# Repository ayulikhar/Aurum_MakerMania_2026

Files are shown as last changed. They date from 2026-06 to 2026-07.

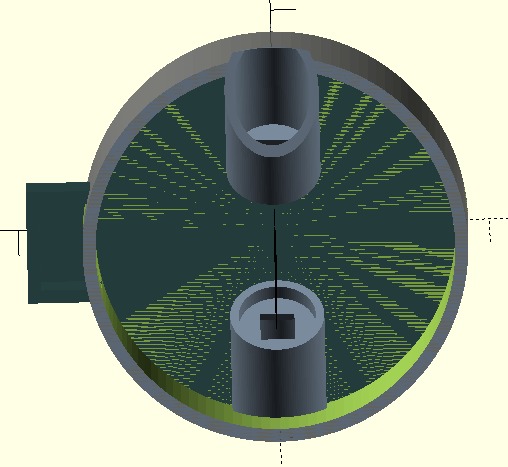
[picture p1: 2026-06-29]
images/WhatsApp Image 2026-06-24 at 1.21.38 PM.jpeg

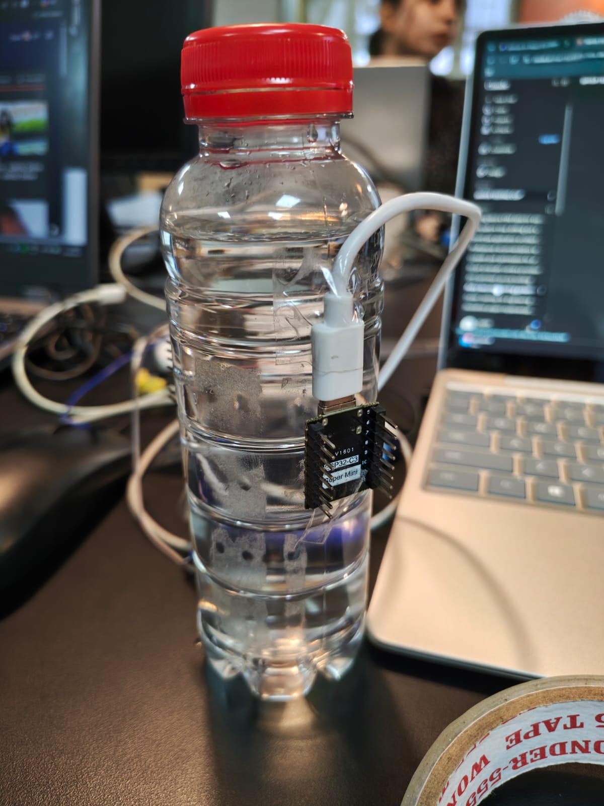
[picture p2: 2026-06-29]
images/WhatsApp Image 2026-06-27 at 2.15.06 PM.jpeg

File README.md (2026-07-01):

# Aurum MAKERMANIA 2026

## Innovation Project Workbook

> Program Duration: 1 June 2026 – 4 July 2026
>
> Location: MBF Tinkerers' Lab 007
>
> Team Size: 3–5 Students
>
> Goal: Identify a real-world problem and develop an innovative, patentable, and implementable solution.

---

# 1. Team Identity

## 1.1 Team Name and Photo
WhatsApp Image 2026-06-06 at 12 39 31 PM

---

## 1.2 Team Members

| Name | Role | Skills |
| ---- | ---- | --- |
| Ayush Likhar | Collaborator | Hardware |
| Kartik Phadale | Collaborator | Software |
| Meezaan Malik | Collaborator | Design |

---
# Useless Product Link
https://youtu.be/-Jjdkq18U_4
---
# SCAMPER PROJECT 
https://1drv.ms/p/c/c6b1c4d0bfa1a2d2/IQAcbvFI4a4YR6u9E6l7ya9vAZwWg2kD-QSHdWZtFSUPwtM?e=thSRv1
---
# 2. Problem Discovery

## 2.1 Observation Area

Where did you conduct your observations?

* Hostel
* Canteen
* Workshop
* Hospital
* Public Transport
* Home
* Other

---

## 2.2 AEIOU Observation Sheet

### Activities

What are users doing?

Filling drinking water from taps, borewells, or overhead tanks before consuming
Storing water in containers such as pots, buckets, and plastic cans for daily household use
Manually checking water appearance against light or checking by smell before use
Operating water purifiers (RO/UV) with little understanding of actual output quality
Buying packaged drinking water due to distrust of the tap supply

### Environment

What conditions affect them?

Urban apartments and peri-urban areas with inconsistent municipal supply quality
Rural homes relying on borewell or hand-pump water with unknown contamination levels
Post-monsoon periods where sediment and biological load spike in surface water
Kitchens and storage areas where any device must survive humidity and incidental water exposure
Frequent power outages in many regions, meaning the device cannot depend on mains supply during testing

### Interactions

Who or what are they interacting with?

Water sources including taps, tanker trucks, borewells, and stored containers
Household members, particularly mothers making water safety decisions for children
Water purifiers (RO/UV) that users trust without verifying actual output quality
Municipality or tanker suppliers, where complaints are made verbally with no data to support them
Neighbours and community members, through informal word-of-mouth about water quality

### Objects

Plastic storage containers and overhead tanks as primary water holding vessels
RO/UV purifiers that are trusted but unmonitored for actual output quality
TDS pen meters used by some urban households, though the numeric output is rarely understood
Packaged water bottles purchased as a costly substitute when tap water is distrusted
No pH or turbidity measurement tools are present in a typical household — this is the gap this device addresses

### Users

Homemakers (25–55 years): primary decision-makers for household drinking water, generally non-technical
Renters in urban areas: no control over plumbing infrastructure, high need to verify supplied water
Rural households: borewell-dependent, no access to laboratory testing, often low literacy
Parents with young children: heightened concern, willing to act on clear safety signals
Small food businesses such as tea stalls and tiffin centres needing quick, repeatable daily water checks

---

## 2.3 Observation Log

| Observation | Evidence | Pain Point |
| --- | --- | --- |
| | | |
| | | |

---

# 3. User Research

## 3.1 Interview Summary

Number of users interviewed: ______

## 3.2 Key Quotes

1.

2.

3.

---

## 3.3 User Persona

### Name

### Age

### Occupation

### Goals

### Frustrations

### Needs

---

# 4. Problem Framing

## Problem Statement

Household users, particularly in Indian urban and semi-urban contexts, have no affordable, reliable, and easy-to-use tool to simultaneously assess multiple water quality parameters at the point of use. As a result, they either consume potentially unsafe water without knowing it, or spend unnecessarily on packaged alternatives. Existing solutions are either single-parameter, too expensive, or require technical knowledge to interpret.

---

## How Might We Questions

1. How might we make water quality assessment as simple as filling a cup, with no technical skill required?
2. How might we measure pH, turbidity, and TDS simultaneously without submerging any electrical components in the water?
3. How might we deliver a multi-parameter water quality device at a unit cost low enough for household adoption across income levels?
---

## Opportunity Ranking

| Criteria | Score |
| --- | ----- |
| Severity | 9 |
| Frequency | 9 |
| Feasibility | 7 |
| Novelty | 9 |
| Market Potential | 8 |
| Total | 42 |

---

# 5. Solution Ideation

## Brainstormed Ideas

| Idea | Advantages | Challenges |
| ---- | --- | --- |
| Arterial Aging Ring  | Can detect arterial health, blockages  | Miniature, Accuracy |
| Compression Stockings | Varicose Veins Relief | Graduated compression accuracy, cost-effective production |
| Trash Compactor | Increased Storage Efficiency, Odour Removal  | Proof of Concept |
| River Cleaaning UAV | Pilotless water body cleaning | Limited large-scale capacity, autonomous navigation challenges |
| Touch Sensing Glove with Haptics | Brings Realistic Feedback | Application and comfort Challenges |
| Tamperproof Weighbridge | Ensures fraud free loading | System Integration |

---

## Selected Concept

Waterborne illness remains a leading cause of disease in Indian households. Simultaneously, no single affordable device measures all critical parameters together. Water can pass TDS comfortably and still be dangerously acidic or heavily contaminated with fine particulates. The parameters are interdependent but are currently measured in isolation if at all. 
Each subsystem is a self-contained learning module. The TDS refractometry covers physical optics and numerical methods. Turbidity covers photonics and analog circuit design. Together they represent a systems integration challenge that mirrors professional product development. 

---

# 6. System Design

## High-Level Description

The solution provides a cup-based turbidity testing system that accepts a water sample, measures its cloudiness through an embedded sensor, and displays or transmits the resulting water quality assessment.

---

## Block Diagram



---

## Inputs

|Input | Importance |
|---- |--- |
| Water Sample in Cup | Main physical input |  
| Colorimetry | pH Value |
| RGB Sensor | pH level determination |
| nRF24L01  | Transmission of EM waves |

---

## Outputs

| Sensors | Output |
|----- |----- |
|LCD / Display Output | Turbidity reading, clarity percentage, status (clear, cloudy, dirty) |
|Buzzer | Alert |

---

# 7. Technical Planning

## Electronics

| Component | Purpose |
| --- | --- |
| ESP32 NodeMCU Development Board | System timing, nRF24 SPI interface, I2C polling, hardware timers for optical tracking |
| ADS1115 16-Bit I2C ADC Module | Overcomes the noisy, non-linear internal ADC of the ESP32 to capture microvolt changes from the custom pH sensor |
| Double-Sided Copper-Clad PCB Board Blank | Slashed into small rectangles to create the physical sensing pad and reference pad surfaces.  |
| Concentrated Sodium Hypochlorite (Bleach) + Sandpaper | Used as an oxidizer on the copper track to grow the reactive copper-oxide (CuO) sensing layer|
| 5V 650nm Red Laser Diode (6mm diameter, 5mW) |Projects a tight optical beam through the diagonal entry tunnel. |
| Glass Microscope Coverslips (0.13 - 0.17mm thick) | Acts as the optically flat, scratch-resistant window sealed into the 45-degree pocket |
| TSL1401CL Linear Photodiode Array (128 Pixels) | Captures the high-resolution spatial displacement of the laser beam spot down to fractional subpixels |
| Dual Light-Dependent Resistors (LDRs) + Razor Blade | Ultra-scalable alternative: Two matching LDRs separated by an opaque blade edge to form a basic analog differential balance pair |
| 2x nRF24L01+ 2.4 GHz Transceiver Modules | Mounted entirely outside the cup walls to measure signal amplitude drop (RSSI) through the liquid column.|
| 2x 2.4 GHz PCB Directional Patch Antennas | Focuses the RF energy straight through the liquid column, minimizing external multipath interference |
| DS18B20 Waterproof Temperature Probe | Real-time thermal tracking to dynamically recalculate the temperature-dependent Nernst slope for the pH firmware|
| Assorted Resistors (10kΩ, 4.7kΩ), 0.1µF Capacitors | Pull-up resistors for the 1-Wire temperature bus, voltage dividers for LDR paths, and decoupling caps for RF rails |
| Clear Marine-Grade Silicone RTV or 2-Part Transparent Epoxy | Creates a reliable waterproof seal around the glass coverslip insert and wire pass through tunnels |
| Turbidity Sensor with Module | Measures water clarity by dropping an infrared emitter/receiver probe directly into the liquid. |
| pH-4502C Liquid pH Sensor Module + E-201-C Glass Combination Electrode | Measures hydrogen ion activity using a traditional glass bulb probe with a BNC connector interface board 
| TP4056 , Lipo cells | |

---
## Software

| Tool | Purpose |
| ---- | --- |
| KiCAD |  PCB Design |
| OpenSCAD | 3D Model Design  |
| BambuLab | 3D print  |

---

## Mechanical / CAD

WhatsApp Image 2026-06-24 at 1 21 38 PM (1)

A vertically oriented, two-section cylindrical assembly designed to house a multi-parameter water quality sensing system. The complete assembly stands 190 mm tall. A hollow open-top cylinder of 140 mm height forming the primary water-holding vessel. The inner diameter provides sufficient water volume for accurate optical measurements while maintaining a compact handheld form factor.                                                                             The floor of the cup body incorporates a raised conical deflector structure housing two laser alignment tunnels, each inclined at 45° to the vertical axis.  A large curved ramp surface sweeps from the inner wall down toward the central aperture, redirecting the laser beam from its horizontal entry path to a 45° angle through the water column. A second symmetric tunnel on the opposite side captures the refracted beam and routes it to the external photo diode array. The floor geometry is fully integrated into the cup body as a single printed part, eliminating alignment error between the optical axis and the deflector surface. The housing sits on a flat circular base and contains the primary electronics bay for the ESP 32 micro-controller, signal conditioning circuitry, and power management components. Four rectangular extrusions protrude from the outer diameter of the assembly at the cup-to-housing interface, each 40 mm in length and separated by 10 mm gaps. These housings accommodate the lateral optical and sensing components 

---

# 8. Prototype Development

## Version 1

Description: 

Two ESP32-C3 Supermini boards configured in an ESP-NOW Master-Slave architecture, placed on opposite sides of a water-filled cup. The Master transmitted packets at fixed maximum TX power while the Slave measured RSSI values, attempting to correlate signal attenuation with turbidity levels.

Lessons Learned:
- RSSI behaved opposite to expectation — signal was stronger through turbid water than clean water due to particles displacing water and reducing bulk dielectric loss
- At drinking water turbidity ranges (0–500 NTU), particle volume fraction is below 0.002%, making the dielectric change too small to detect within ESP32's 1 dBm RSSI resolution floor
- RF signal leaked around the water container rather than through it, meaning ambient reflections from walls and surfaces dominated the readings
- This is a fundamental physics constraint, not a fixable engineering or code problem
---

## Version 2

Description:
Same ESP32-C3 Supermini hardware reprogrammed with a power sweep method. Instead of reading RSSI, the Master stepped TX power down from 21 dBm to 5 dBm in 8 discrete levels, sending 10 packets at each level. The Slave sent ACK packets back reporting reception count per level. The power threshold at which packet reception dropped below 50% was used as a turbidity proxy.

Lessons Learned:

- Channel mismatch error (Peer channel is not equal to home channel) required switching from WiFi.channel() to esp_wifi_set_promiscuous() + esp_wifi_set_channel() for correct channel locking
- Power sweep output was identical regardless of water presence, turbidity level, or board orientation — confirming that even the binary threshold method cannot resolve turbidity changes at the signal magnitudes available over a 5cm path at 2.4GHz
- RF shielding with aluminum foil was attempted to force signal through water only, with no measurable improvement
- The 103 dBm of remaining link budget after water attenuation is too large — turbidity-induced loss is buried orders of magnitude below the noise floor
---
DOCUMENTATION LINK: <https://docs.google.com/document/d/1FKyJl6S2ex2YoXibOfduwqcpoKrc6gzWdBtXB66RiD4/edit?usp=sharing>
## Final Prototype

Description:

In progress
---

# 9. Testing & Validation

## Testing Plan

| Test | Success Criteria |
| ---- | --- |
| | |
| | |

---

## User Feedback

| User | Feedback | Action Taken |
| ---- | --- | --- |
| | | |

---

# 10. Innovation Assessment

## Existing Solutions

List competing products.

---

## What Makes This Different?

---

## Innovation Score

| Parameter | Score |
| --- | ----- |
| Novelty | |
| Technical Depth | |
| Feasibility | |
| Impact | |
| Scalability | |

---

# 11. Intellectual Property

## Prior Art Search

Patents / Products Found:

---

## Novel Features

1.

2.

3.

---

## Provisional Patent Draft

### Title

### Abstract

### Problem

### Solution

### Claims

---

# 12. Business & Deployment

## Target Users

---

## Estimated Cost

---

## Market Opportunity

---

## Sustainability Considerations

---

# 13. Final Demonstration

## Prototype Images

Insert photos.

---

## Demonstration Video Link

---

## GitHub Repository

---

## Presentation Link

---

# 14. Reflection

## What Worked Well?

---

## What Failed?

---

## Key Learnings

---

## Next Steps

* Patent Filing
* Startup Exploration
* Product Development
* Research Publication
* Competition Submission

---

# 15. Final Deliverables Checklist

* Problem Discovery Complete
* User Interviews Complete
* Persona Created
* Problem Statement Finalized
* System Design Complete
* Prototype Demonstrated
* Testing Completed
* Patent Draft Prepared
* Presentation Submitted
* GitHub Repository Updated

---

# MAKERMANIA FINAL PITCH

Each team will present:

1. Problem
2. User Research
3. Insights
4. Solution
5. Prototype Demo
6. Innovation & Patentability
7. Future Roadmap

Presentation Time: 5 Minutes

Q&A: 3 Minutes

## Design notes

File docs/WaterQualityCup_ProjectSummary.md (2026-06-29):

# Solid-State Water Quality Testing Cup
## Project Summary — Teammate Reference Document

> **Purpose:** This document summarises all design decisions, physics, firmware, hardware, and experimental results from the project development chat. Use this as your starting point for continuing work.

---

# SECTION 1 — PROJECT OVERVIEW

## Core Concept
A multi-parameter water quality testing device shaped like a cup. The defining engineering constraint is **100% solid-state, non-contact architecture** — no electrodes, no glass probes, no electrical contact between sensing electronics and the water being tested.

## Why This Architecture
- Eliminates ground loops between sensors when multiple are submerged together
- Eliminates sensor fouling (probes getting dirty)
- Eliminates fragile glass pH bulbs
- Drives unit cost toward mass-manufacturing economics
- Genuinely novel — no prior art found for this specific combination

## Three Sensing Subsystems

| Subsystem | Parameter | Method |
|---|---|---|
| A | Turbidity | RF attenuation / CSI phase (2.4GHz) |
| B | TDS (Total Dissolved Solids) | Dual-wavelength laser refractometry |
| C | pH, Chlorine, Hardness | Optical colorimetry (phenol red dye + RGB sensor) |

---

# SECTION 2 — PATENT STATUS

## Patentability Assessment (India, Patents Act 1970)

| Subsystem | Novelty | Strength |
|---|---|---|
| RF/CSI turbidity method | High — no prior art found | Strongest independent claim |
| Laser refractometry TDS (specific geometry) | Medium — principle known, geometry novel | Strong dependent claim |
| Colorimetric pH (ratiometric spectral) | Low standalone | Part of combination claim |
| Entire cup system (combination) | High | Primary patent claim |

## Key Filing Facts
- **No prototype required** for provisional filing
- Theory, mathematics, and figures are sufficient at provisional stage
- File provisional first (costs ~₹1,600 on IP India portal)
- 12-month window after provisional to build PoC and file complete specification
- **Do not publish or present publicly before filing**

## Provisional Specification Must Include
1. Cross-section diagram of cup with all three subsystems labelled
2. Block diagram of electronics
3. Mathematical description of each sensing method
4. RF attenuation theory + calibration curve concept
5. Snell's Law geometry for refractometry
6. RGB-to-HSV or ratiometric spectral conversion for pH
7. Informal claims list (formal claims required only in complete spec)

## Strongest Patent Claims
1. The cup-form-factor solid-state multi-parameter sensing architecture
2. RF/CSI-based non-contact turbidity sensing through cup walls
3. Dual-wavelength refractometry with mathematical temperature/TDS decoupling
4. Ratiometric spectral pH using dissolved indicator dye

---

# SECTION 3 — HARDWARE ARCHITECTURE

## Microcontrollers

| Board | Role | Notes |
|---|---|---|
| ESP32-C3 Supermini #1 | RF Turbidity — Master/Tx | Transmits ESP-NOW beacons through water |
| ESP32-C3 Supermini #2 | RF Turbidity — Slave/Rx | Measures RSSI / CSI, outputs to Serial Monitor |
| ESP32 DevBoard (38-pin, black) | Master MCU | Runs TDS, colorimetric, OLED, BLE |

## Critical Arduino IDE Settings (Both ESP32-C3 Boards)
```
Board:              ESP32C3 Dev Module
USB CDC On Boot:    Enabled  ← MANDATORY or Serial won't work
Upload Speed:       115200
Flash Mode:         DIO
Partition Scheme:   Default 4MB with spiffs
Core version:       3.0.0 or higher  ← MANDATORY for rx_ctrl->rssi
```

## Known Firmware Issues Fixed
- `BOOT_PIN` conflicts with `esp32-hal.h` → renamed to `BTN_BOOT`
- Send callback must use `wifi_tx_info_t*` not `uint8_t*` in core v3
- No `ARDUINO_ISR_ATTR` on ESP-NOW callbacks
- USB-CDC needs 2–3 second wait loop in `setup()` before Serial output

---

# SECTION 4 — TURBIDITY SUBSYSTEM (RF / CSI)

## Current Status: RSSI Method Has Physics Problems

### What Was Tested
Two ESP32-C3 Superminis mounted on opposite sides of a 5cm diameter PET bottle filled with water. ESP-NOW packets fired at 20/second. RSSI measured from `recv_info->rx_ctrl->rssi` in receive callback.

### Experimental Results
```
Clean water:          -38 dBm baseline (through cup, correct geometry)
Turbid water (flour): -25 dBm (RSSI went UP — wrong direction)
Air (no water):       -29 dBm
```

### Why RSSI Goes The Wrong Direction
At 2.4GHz, **water is the absorber, not the particles.** Adding suspended particles displaces water molecules, reducing bulk dielectric loss of the mixture. More particles = less water in path = less RF absorption = RSSI increases. Particle scattering is negligible because particles (0.1–100µm) are 100–10,000× smaller than the 14.2mm wavelength inside water at 2.4GHz.

### Why Signal Magnitude Is Too Small
At 100 NTU, particles occupy < 0.002% of water volume. The resulting dielectric change is below the ESP32's 1 dBm RSSI resolution floor. This is a fundamental physics constraint, not a fixable engineering problem.

### Physical Setup Problems Found
- Pin headers created air gap between boards and bottle → RF leaked around water
- Reflected paths from desk/laptop/walls dominated over direct through-water path
- No RF shielding on sides of bottle
- Cupping hands helped identify but did not resolve the direction issue

## Three Viable Solutions

### Solution A — Power Sweep Threshold (Implement Now, Same Hardware)
Instead of reading RSSI amplitude, step transmit power down in known increments and find the link margin threshold — the minimum power at which the Slave still receives packets. More turbid water requires higher transmit power to maintain the link.

- Resolution: ~500 NTU (not drinking-water precise)
- Cost: ₹0, same hardware, implementable today
- Patent value: Medium

```cpp
// Master sweeps TX power from max to min
// Slave reports packet reception rate at each power level
// Threshold power = turbidity proxy
const int8_t powerLevels[] = {20, 28, 40, 52, 60, 68, 76, 84}; // ×0.25 dBm
```

### Solution B — LoRa at 868MHz (Better Physics)
At 868MHz, water's dielectric loss is lower, so turbidity signal is relatively larger. Replace ESP32-C3 nodes with SX1276 LoRa modules.
- Cost: ~₹400 for two modules
- Resolution: Better than 2.4GHz, still not NTU-precise
- Patent value: Medium

### Solution C — ESP32 CSI Phase Measurement (Best, Recommended)
**Channel State Information (CSI)** from the ESP32's WiFi radio includes per-subcarrier phase data. Phase changes more than amplitude when turbidity changes because particles affect the real part of permittivity (ε') which RSSI cannot see.

- Requires: Full ESP32 or ESP32-S3 (NOT ESP32-C3 — C3 does not support CSI)
- Your existing black 38-pin ESP32 DevBoard supports CSI
- Resolution: ~100–200 NTU threshold (far better than RSSI)
- Cost: ₹0 — use existing DevBoard
- Patent value: **Strong** — CSI-based liquid turbidity sensing is novel, published research supports the physics

**Recommended next step: Implement CSI on the ESP32 DevBoard.**

## RSSI Firmware (Current Working Code)

### Flashing Order
1. Flash `GET_MAC.ino` to Slave → write down MAC address printed
2. Flash `MASTER.ino` to ESP32-C3 #1 (paste Slave MAC first)
3. Flash `SLAVE.ino` to ESP32-C3 #2
4. Power Master from USB power bank; Slave stays connected to PC

### Key Code Facts
```cpp
// Slave receive callback — RSSI extraction
void onPacketReceived(const esp_now_recv_info_t *recv_info,
                      const uint8_t *data, int len) {
    int8_t rssi = recv_info->rx_ctrl->rssi;  // Range: -120 to 0 dBm
    // Store in ring buffer for median filtering
}

// Master send callback — CORRECT v3 signature
void onPacketSent(const wifi_tx_info_t *info,        // NOT uint8_t*
                  esp_now_send_status_t status) { }

// Both boards must use same channel
const uint8_t WIFI_CHANNEL = 1;  // Change if WiFi congestion on ch.1

// Buffer size increased to 40 (no decoupling caps available)
const uint8_t RSSI_BUFFER_SIZE = 40;
```

### NTU Conversion (After Calibration)
```
NTU = A × RSSI² + B × RSSI + C
```
Coefficients A, B, C are placeholders (0.0) until lab calibration with known NTU standards. RSSI values are real and accurate immediately.

### Temperature Compensation
```
RSSI_compensated = RSSI_raw - (K_TEMP × (T_water - 25.0))
K_TEMP = 0.2 dBm/°C (starting estimate, refine during calibration)
Apply compensation BEFORE polynomial conversion, not after.
```

---

# SECTION 5 — TDS SUBSYSTEM (LASER REFRACTOMETRY)

## Physics

The cup has a 45° diagonal laser tunnel. The laser enters the water perpendicular to the 45° glass coverslip (zero bending at entry). The beam travels at 45° through the water and exits through the opposite cup wall at ~70° from horizontal.

**Key geometric advantage:** At 70° exit angle, the geometric amplification factor is 8.7×, giving ~60µm beam displacement per 1000 ppm TDS at 20mm detector standoff. This is detectable with the BPW34 differential pair.

## Dual-Wavelength Method

Two lasers (650nm red + 405nm violet) travel the same path. They exit at slightly different angles due to chromatic dispersion:
```
Red (650nm):    exit angle = 70.2°
Violet (405nm): exit angle = 71.8°
Spot separation at 20mm standoff: 6.2mm vertical
```

### Why Two Wavelengths
1. **Mechanical noise cancellation:** Both beams shift equally when cup vibrates — their separation is immune to physical disturbance
2. **Temperature/TDS decoupling:** TDS and temperature affect the two wavelengths in different ratios, allowing a 2×2 matrix solve for both simultaneously — no temperature sensor required
3. **Stronger patent claim:** Novel dual-observable ratiometric measurement

### 2×2 Matrix Solution
```
D_red    = α_red    × ΔTDS + β_red    × ΔT
D_violet = α_violet × ΔTDS + β_violet × ΔT

Constants:
α_red    = 1.65×10⁻⁷  (dn/dC at 650nm, per ppm)
α_violet = 1.80×10⁻⁷  (dn/dC at 405nm, per ppm)
β_red    = -9.5×10⁻⁵  (dn/dT at 650nm, per °C)
β_violet = -10.0×10⁻⁵ (dn/dT at 405nm, per °C)
DET      = (α_red × β_violet) - (α_violet × β_red) = 6.0×10⁻¹⁴

Solve by Cramer's Rule:
ΔTDS = (β_violet × dn_red - β_red × dn_violet) / DET
ΔT   = (α_red × dn_violet - α_violet × dn_red) / DET
```

## Detector: BPW34 Differential Pair (Replaces TSL1401CL)

TSL1401CL was not available. BPW34 differential pairs are used instead — actually better for small displacement signals.

```
Two BPW34 diodes mounted vertically (PD_A above PD_B)
Gap between faces: 0.3–0.5mm (use cardstock shim during assembly)
Red cellophane filter over red pair
Violet cellophane filter over violet pair
Gap must be VERTICAL because beam moves vertically with TDS change

Signal: (I_A - I_B) / (I_A + I_B)
Ratiometric — immune to laser power drift
```

## Signal Conditioning Circuit
```
BPW34 → LM358 TIA (transimpedance amplifier)
Feedback resistor: 1MΩ
Stability capacitor: 10pF across feedback resistor
Output voltage: I_photodiode × 1MΩ
ESP32 ADC reads output voltage (GPIO32, 33, 34, 35 — all ADC1)
```

## Coverslip Alignment Test
```
Shine laser through tunnel with coverslip in place (dry, no water)
If reflection goes straight back into laser tunnel → coverslip angle correct ✅
If reflection goes sideways → adjust coverslip angle with paper shim ❌
Perpendicular incidence produces retroreflection
```

## Calibration
Prepare NaCl solutions at 100, 250, 500, 1000, 2000 ppm.
Record differential ratio at each concentration.
Run Python regression to find K_SENS_RED and K_SENS_VIOLET.
Use Cramer's Rule to solve for TDS and temperature simultaneously.

---

# SECTION 6 — pH SUBSYSTEM (COLORIMETRY)

## Method: Phenol Red Dissolved Dye + TCS34725 RGB Sensor

Add a microdrop of phenol red solution to the water sample. The dye changes colour based on pH:
```
pH < 6.8  → Yellow
pH = 7.0  → Orange
pH > 8.4  → Red
```
This range (6.8–8.4) covers the entire WHO drinking water acceptability window exactly.

## Why Not Test Strips
- Strips cost ₹2–5 each; phenol red costs < ₹0.05/test
- Dissolved dye gives uniform optical path; strips have uneven surfaces
- Phenol red shelf life: 3–5 years

## Where to Get Phenol Red in Mumbai
- SRL Chemicals / Byculla chemical market
- HiMedia, Merck India on IndiaMART
- Your college biology/microbiology lab likely has it — ask before buying

## Ratiometric pH Calculation
```cpp
// TCS34725 reads R, G, B, Clear channels
// Normalise against Clear to remove LED intensity dependence
float rNorm = (float)r / (float)c;
float bNorm = (float)b / (float)c;

// Ratio rises monotonically with pH
float ratio = rNorm / (rNorm + bNorm);

// Convert to pH via calibration polynomial
float pH = (CAL_A * ratio * ratio) + (CAL_B * ratio) + CAL_C;
```

Using ratio instead of raw values makes reading immune to LED brightness variation — same principle as HSV hue method.

## Accuracy
- TCS34725 + phenol red + ratiometric: ±0.2–0.4 pH
- Better than test strips (±0.5–1.0)
- Sufficient for WHO 6.5–8.5 drinking water standard

## Calibration Required
pH 4.0, 7.0, and 10.0 buffer sachets (~₹80 each, one-time purchase).
Dissolve phenol red in each buffer at same concentration as your measurement setup.
Record ratio value for each known pH.
Fit 2nd-order polynomial in Python.

---

# SECTION 7 — CUP DESIGN (3D PRINTED)

## Already Built Features
- 45° diagonal laser tunnel (sealed, light-tight)
- Glass coverslip pocket at base of tunnel (45° angle)
- Two rectangular side cutouts for RF node mounting
- Circular colorimetric sensor window on side wall
- Removable base plate for assembly access

## Confirmed Beam Path
- Laser enters water perpendicular to 45° coverslip → no bending at entry
- Beam travels at 45° through water column
- Exits through opposite cup wall at ~70° from horizontal
- All refraction happens at the exit wall — this is where TDS is measured

## Detector Standoff Bracket (To Be Printed)
- Mounts on outside of cup wall opposite laser tunnel
- 20mm standoff from outer wall surface to photodiode faces
- Upper position: violet BPW34 pair
- Lower position: red BPW34 pair
- Vertical separation between pair centres: 6.2mm

## Assembly Sequence
```
1. Install coverslip → verify with retroreflection test
2. Install laser in tunnel → dry fire, confirm beam exits
3. Physical beam trace → mark exit point on cup wall
4. Assemble BPW34 pairs → mount at exit point
5. Wire to LM358 TIA circuit on external perfboard
6. Connect to ESP32 ADC
7. Fill with distilled water → run baseline calibration
8. Fill with known NaCl solutions → derive K_SENS
9. Install RF nodes in side pockets
10. Install TCS34725 + phenol red at colorimetric window
```

---

# SECTION 8 — COMPLETE BILL OF MATERIALS

| # | Component | Spec | Qty | Est. Cost (₹) |
|---|---|---|---|---|
| 1 | ESP32-C3 Supermini | 2.4GHz, ESP-NOW | 2 | 360 |
| 2 | ESP32 DevBoard (black) | 38-pin, dual-core | 1 | 350 |
| 3 | TCS34725 RGB sensor | I2C, IR filter | 1 | 280 |
| 4 | Laser diode, 650nm red | 5mW, 5V, with driver | 1 | 100 |
| 5 | Laser diode, 405nm violet | 5mW, 5V, with driver | 1 | 200 |
| 6 | BPW34 photodiode | Silicon PIN, TO-5 | 4 | 112 |
| 7 | Silicone sealant | Neutral cure, clear | 1 tube | 120 |
| 8 | 100µF electrolytic cap | 10V, radial | 2 | 10 |
| 9 | 100nF ceramic cap | 50V | 4 | 8 |
| 10 | 10µF electrolytic cap | 10V, radial | 4 | 20 |
| 11 | LM358 dual op-amp | DIP-8, single supply | 2 | 24 |
| 12 | Resistor 1MΩ | ±1%, 0.25W | 8 | 8 |
| 13 | Resistor 10kΩ | ±5%, 0.25W | 3 | 3 |
| 14 | Resistor 470Ω | ±5%, 0.25W | 3 | 3 |
| 15 | Resistor 330Ω | ±5%, 0.25W | 5 | 5 |
| 16 | N-MOSFET 2N7000 or BS170 | TO-92 | 3 | 24 |
| 17 | Microscope coverslips | 22×22mm, #1 thickness | 1 pack (50) | 120 |
| 18 | White LED, high CRI | CRI≥90, 5600K | 2 | 30 |
| 19 | Phenol red powder | Lab grade, 5g | 1 | 150 |
| 20 | pH buffer sachet pH 4.0 | Calibration standard | 1 | 80 |
| 21 | pH buffer sachet pH 7.0 | Calibration standard | 1 | 80 |
| 22 | pH buffer sachet pH 10.0 | Calibration standard | 1 | 80 |
| 23 | Clear acrylic sheet, 3mm | Cut to 30×20mm | 1 piece | 30 |
| 24 | 18650 Li-Ion cell | 3.7V, ≥2000mAh | 1 | 200 |
| 25 | TP4056 charging module | With protection | 1 | 35 |
| 26 | MT3608 boost converter | 3.7V→5V adjustable | 1 | 45 |
| 27 | 7semi / AMS1117-3.3V LDO | 1A output | 1 | 15 |
| 28 | OLED display | 0.96", SSD1306, I2C | 1 | 120 |
| 29 | Jumper wires | M-M and M-F, 20cm | 1 set | 60 |
| 30 | Breadboard | 830 tie-points | 1 | 80 |
| 31 | Perfboard | 5×7cm | 2 | 50 |
| 32 | 5-minute epoxy | Two-part, clear | 1 pack | 80 |
| 33 | M2 screws and nuts | 6mm | 1 pack | 30 |
| 34 | NaCl (table salt) | Food grade | 1 pack | 20 |
| 35 | Kaolin clay | Fine powder | 100g | 50 |
| 36 | Distilled water | 1 litre | 2 bottles | 50 |
| | **TOTAL** | | | **~₹3,050** |

## LDO Note
AMS1117-3.3V and 7semi 5V→3.3V 1A LDO are functionally identical for this application. Use whichever is available. Neither is needed for the turbidity prototype (both C3 Superminis self-regulate from USB). Only needed when full sensor suite is connected to DevBoard.

## Capacitor Note
100pF capacitors (currently available) are useless for power decoupling — too small by 3–6 orders of magnitude. Work without capacitors for now by:
- Powering Master and Slave from separate USB sources
- Increasing RSSI_BUFFER_SIZE to 40 in firmware
- Order 100µF and 100nF caps with next component batch

---

# SECTION 9 — POWER ARCHITECTURE

```
18650 Li-Ion (3.7V)
        │
        ├──→ TP4056 (charging)
        │
        ├──→ MT3608 Boost → 5V rail → Lasers + White LED
        │                             (gated via MOSFET)
        │
        └──→ ESP32 DevBoard VIN → onboard AMS1117 → 3.3V
                                   → Sensors (TCS34725, OLED, BPW34 circuit)
```

ESP32 DevBoard has its own onboard LDO. External LDO only needed for a dedicated clean analog sensor rail separate from the DevBoard's noisy WiFi-sharing rail.

---

# SECTION 10 — CALIBRATION PROCEDURES

## Turbidity (RF — After Physics Solution is Chosen)
1. Prepare kaolin clay suspensions at 0, 50, 100, 250, 500 NTU
2. Get reference NTU values certified by a water testing lab (CPCB lab)
3. Record RSSI (median) for each standard at 25°C
4. Run Python polynomial regression → get A, B, C
5. Determine K_TEMP by measuring RSSI at 10°C, 15°C, 25°C, 35°C with same sample

## TDS (Refractometry)
1. Prepare NaCl solutions: 100, 250, 500, 1000, 2000 ppm
2. Verify concentrations with a TDS pen meter (₹300)
3. Record differential ratio (red and violet) for each
4. Run Python regression → get K_SENS_RED, K_SENS_VIOLET
5. Verify temperature decoupling by testing at 15°C and 35°C

## pH (Colorimetry)
1. Add phenol red to pH 4.0, 7.0, 10.0 buffer solutions at standard concentration
2. Read TCS34725 R, G, B, C for each
3. Compute ratio = rNorm / (rNorm + bNorm)
4. Fit 2nd-order polynomial ratio → pH
5. Get CAL_A, CAL_B, CAL_C

## Python Regression Script (All Subsystems)
```python
import numpy as np
from sklearn.metrics import r2_score

# Replace with your actual data
x = np.array([-55, -62, -68, -75, -85])  # RSSI or ratio values
y = np.array([0, 50, 100, 250, 500])      # Known NTU or ppm or pH

coeffs = np.polyfit(x, y, 2)  # 2nd-order polynomial
y_pred = np.polyval(coeffs, x)
r2     = r2_score(y, y_pred)

print(f"A={coeffs[0]:.6f}, B={coeffs[1]:.6f}, C={coeffs[2]:.6f}")
print(f"R² = {r2:.4f}  (target > 0.95)")
# Paste A, B, C into firmware
```

---

# SECTION 11 — PATENT FILING GUIDE

## Immediate Action: File Provisional on IP India Portal
**Website:** https://ipindiaonline.gov.in

**Cost:** ~₹1,600 for individual applicant (e-filing)

**Forms needed:**
- Form 1: Application for Grant of Patent (applicant details, inventor details)
- Form 2: Provisional Specification (your description document)

**What to include in provisional specification:**
1. Title (technical, not marketing)
2. Background (problem with existing electrochemical sensors)
3. Summary (three-subsystem non-contact architecture)
4. Figure descriptions (cross-section, block diagram, calibration curves)
5. Detailed description of each subsystem with physics and math
6. Informal claims list

**12-month window after provisional:**
- Month 1–3: Build and validate prototype
- Month 5–7: Write complete specification
- Month 7–8: Patent Agent reviews and drafts formal claims
- Before Month 12: File complete specification (Form 2, complete)

**Patent Agent fee:** ₹15,000–₹40,000 for formal claim drafting
**Find agents at:** https://ipindiaonline.gov.in/patentSearch/searchAgentPatent.aspx

---

# SECTION 12 — CURRENT EXPERIMENTAL RESULTS

## Turbidity RF Test (Completed)

| Condition | RSSI Reading | Notes |
|---|---|---|
| Clean water (bottle, correct geometry) | -38 dBm | Good baseline, strong signal |
| Turbid water with flour | -25 dBm | RSSI went UP — physics problem |
| Air baseline | -29 dBm | Less attenuation than water as expected |

**Conclusion:** RSSI method confirmed not suitable for drinking water turbidity range. CSI phase method recommended as replacement.

## Packet Statistics
- Drop rate in initial test: 9.2% — too high, switch from channel 1 to channel 6 or 11
- Drop rate after bench test: 2.7% — acceptable
- RSSI stability: ±2 dBm with buffer=40, no capacitors — good

---

# SECTION 13 — NEXT STEPS (PRIORITY ORDER)

## Immediate
1. **Implement CSI on ESP32 DevBoard** for turbidity — replaces RSSI method
2. **Change WiFi channel from 1 to 6** in both Master and Slave firmware to reduce packet drop rate
3. **Source IR LED (850nm, ₹15)** as backup optical turbidity method

## Short Term
4. Build BPW34 differential pair detector bracket for TDS subsystem
5. Install laser modules and coverslip in 3D printed cup
6. Physical beam trace to find exit point
7. Run TDS calibration with NaCl solutions

## Medium Term
8. Build phenol red + TCS34725 pH subsystem
9. Calibrate pH with buffer solutions
10. Full system integration test
11. File provisional patent

## Before Patent Filing
12. Collect calibration curves for all three subsystems
13. Run validation against reference instruments
14. Take professional photographs of assembled device
15. Draw formal cross-section figures with reference numerals

---

# SECTION 14 — RESOURCES AND CONTACTS

## Component Sources (Mumbai)
| Item | Where |
|---|---|
| Electronics components | Robu.in, Lamington Road, SP Road |
| Phenol red powder | Byculla chemical market, SRL/HiMedia on IndiaMART |
| pH buffer sachets | Same as above, or college chemistry department |
| Kaolin clay | Pottery suppliers near Dharavi/Kurla |
| Distilled water | Any pharmacy |
| Microscope coverslips | Scientific suppliers near CSMT or college lab |

## Key Reference Links
- IP India patent filing: https://ipindiaonline.gov.in
- Patent agent search: https://ipindiaonline.gov.in/patentSearch/searchAgentPatent.aspx
- ESP32 Arduino core (v3.x required): https://github.com/espressif/arduino-esp32
- ESP-NOW documentation: https://docs.espressif.com/projects/esp-idf/en/latest/esp32c3/api-reference/network/esp_now.html

## Funding Opportunities After Patent Filing
- DST NIDHI PRAYAS Grant: ₹10 lakh for student prototype development
- Atal Innovation Mission (AIM): Incubation + seed funding
- SINE IIT Bombay: Technology transfer and startup incubation
- BIRAC SITARE: Health/environment tech student startups

---

*Document generated from project development conversation. All physics, firmware, calibration procedures, and experimental results reflect work completed as of the conversation date. Teammate continuing this work should start from Section 13 (Next Steps) and refer back to relevant sections as needed.*

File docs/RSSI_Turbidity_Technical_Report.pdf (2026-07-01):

RF-RSSI Turbidity Sensing | Solid-State Water Quality Testing Cup Project

TECHNICAL RESEARCH REPORT

# RF-RSSI Based Turbidity Sensing

Hypothesis, Theoretical Basis, Experimental Results, Findings and Alternative Strategies

Solid-State Water Quality Testing Cup Project

VESIT, Mumbai University | Electronics and Telecommunication Engineering
B.Tech Batch 2024-2028

## Table of Contents

## 1. Hypothesis

This investigation was founded on the following hypothesis:

Primary Hypothesis
The received signal strength (RSSI) of a 2.4 GHz ESP-NOW radio link transmitted through a water column will decrease monotonically and measurably as the turbidity of that water column increases, such that RSSI may be used as a surrogate measurement for turbidity in NTU after empirical calibration.

This hypothesis was motivated by the broader design mandate of the Solid-State Water Quality Testing Cup project, which requires all sensing subsystems to operate without any electrical contact between sensing electronics and the water under test. Optical turbidity sensors require submerged optical components that are susceptible to fouling. The RF method, by placing radio transceivers on the exterior of the cup wall, offers a completely non-contact architecture and was therefore selected for investigation as the turbidity sensing channel.

## 2. Theoretical Basis

### 2.1 The Physics of 2.4 GHz RF in Water

Water is a polar molecule. Its oxygen and hydrogen atoms carry partial negative and positive charges respectively, forming a permanent electric dipole. When an electromagnetic wave at 2.4 GHz passes through liquid water, it exerts an oscillating electric field that forces these dipole molecules to reorient 2.4 billion times per second. This rotational friction dissipates kinetic energy from the wave as heat, attenuating the RF signal.

This phenomenon is quantified by the complex relative permittivity of water:

e_r = e' - j*e''

Where e' is the real part (dielectric constant, governing wave velocity) and e'' is the imaginary part (dielectric loss factor, governing attenuation). At 2.4 GHz and 25 degrees Celsius, pure water exhibits values of approximately:

Parameter | Symbol | Value at 2.4 GHz, 25 C
Dielectric constant | e' | ~78.4

Parameter | Symbol | Value at 2.4 GHz, 25 C
Dielectric loss factor | e'' | ~12.3
Loss tangent | tan(d) = e''/e' | ~0.157
Attenuation coefficient | a | ~295 dB/m

The practical consequence is that a 2.4 GHz radio signal traversing 5 cm of pure water experiences approximately 14.75 dB of attenuation relative to the same path through air. This provides a strong, clearly measurable baseline signal drop when the water-filled cup is placed between the two transceivers.

### 2.2 Expected Effect of Turbidity on RSSI

When suspended solid particles are introduced into the water column, two mechanisms were theorised to affect the RF signal. First, particle scattering was expected to deflect RF energy off-axis, reducing the power reaching the receiving antenna. Second, dielectric displacement was expected to alter the bulk permittivity of the water-particle mixture, changing the attenuation characteristics of the medium. Together, these mechanisms were expected to produce a decrease in RSSI (a more negative dBm value) as turbidity increased.

### 2.3 Why NTU Cannot Be Derived Theoretically

NTU (Nephelometric Turbidity Units) is a strictly optical standard. Under EPA Method 180.1, NTU is defined as the quantity of light scattered at exactly 90 degrees by a suspension when illuminated by a source of specific wavelength (typically 850 nm infrared). Because this definition is rooted in optical scattering behaviour rather than electromagnetic absorption, no direct theoretical relationship between 2.4 GHz RSSI and NTU can be derived from Maxwell's equations alone. Any conversion between the two quantities must therefore be established empirically through calibration against a reference optical nephelometer.

### 2.4 The Empirical Calibration Approach

The proposed calibration methodology followed the Beer-Lambert analogy for signal attenuation through a medium. Because RSSI is already expressed on a logarithmic scale (dBm) and NTU is expressed on a linear scale, a quadratic polynomial regression was expected to yield the best fit between the two quantities:

NTU = A * RSSI^2 + B * RSSI + C

Where A, B, and C are empirically determined calibration coefficients unique to each device geometry. Additionally, a temperature compensation term was incorporated to account for the well-documented temperature dependence of water's dielectric loss factor:

RSSI_compensated = RSSI_raw - (K_temp * (T_water - 25.0))

Where K_temp is a device-specific coefficient expressing RSSI shift per degree Celsius deviation from the 25 degrees Celsius calibration reference, and T_water is the measured water temperature. This compensation is applied to the raw RSSI value before the NTU polynomial is evaluated.

## 3. Experimental Setup

### 3.1 Components Used

Component | Specification | Quantity | Role
ESP32-C3 Supermini | Single-core RISC-V, 2.4 GHz WiFi, ESP-IDF v5 | 2 | RF Master (Tx) and Slave (Rx)
PET Bottle | Standard 500 mL, 50 mm inner diameter | 1 | Water containment vessel
USB-C Cables | Data-capable, not charge- only | 2 | Power and firmware flashing
USB Power Bank | 5V output | 1 | Independent power for Master node
Laptop (PC) | Windows, Arduino IDE 2.x | 1 | Serial Monitor and firmware upload
Tape | Adhesive tape | 1 | Securing boards to bottle surface
Flour / Clay | Common household flour | 1 | Turbidity surrogate for testing
Tap water | Municipal supply, Mumbai | - | Test medium

### 3.2 Pin Connections and Wiring

The two-board system required no inter-board wiring beyond a shared power ground. Each board operated independently via its own USB connection. The following table summarises the pin usage on each node.

MASTER NODE (ESP32-C3 SUPERMINI NO. 1 — TRANSMITTER)

Pin | Function | Connected To | Notes
USB-C | Power and flashing | USB Power Bank (after flashing) | No GPIO connections required
GPIO8 (onboard LED) | Status indicator | Onboard LED (internal) | Blinks 0.5 ms per packet sent

GPIO9
(BTN_BOOT)
| Boot button | Internal pull-up | Renamed from BOOT_PIN to avoid esp32- hal.h conflict
All others | Unused | Unconnected | No peripheral wiring on this node

SLAVE NODE (ESP32-C3 SUPERMINI NO. 2 — RECEIVER AND PROCESSOR)

Pin | Function | Connected To | Notes
USB-C | Power and Serial Monitor | Laptop USB port | Stays connected to PC throughout test
GPIO8 (onboard LED) | Connection status indicator | Onboard LED (internal) | Fast blink = receiving; slow blink = offline

GPIO9
(BTN_BOOT)
| Boot button | Internal pull-up | Same rename convention as Master
All others | Unused | Unconnected | No peripheral wiring on this node

Neither board required any external resistors, capacitors, or passive components for this experiment. Decoupling capacitors (100 uF electrolytic and 100 nF ceramic) were specified in the project design but were unavailable at the time of testing. This absence was partially compensated by increasing the RSSI median filter buffer size from 20 to 40 samples and by powering each board from a separate USB source to eliminate shared power rail noise coupling.

### 3.3 Firmware Architecture

Both nodes ran custom firmware written in Arduino-style C++ targeting the ESP32 Arduino core version 3.3.3, built on top of ESP-IDF v5. The use of core version 3.x was mandatory because the ESP-NOW receive callback signature changed between v2 and v3, and the rx_ctrl->rssi field is only exposed through the new esp_now_recv_info_t struct available in v3.

Key firmware implementation details:

- Master firmware: broadcast ESP-NOW beacon packets at 20 packets per second (50 ms interval) at maximum transmit power (21 dBm). The send callback used the updated wifi_tx_info_t* parameter type required by core v3.
- Slave firmware: received packets via the esp_now_recv_cb callback and extracted RSSI from recv_info->rx_ctrl->rssi as a signed 8-bit integer in dBm. Values outside the physical range of -120 to 0 dBm were rejected.
- A 40-sample circular ring buffer stored incoming RSSI values. An insertion sort median filter was applied to this buffer every 1000 ms to produce a stable filtered RSSI output.
- Temperature compensation was implemented as: RSSI_comp = RSSI_raw - (0.2 * (T - 25.0)), applied before the NTU polynomial evaluation.
- Both nodes locked to WiFi channel 1 via esp_wifi_set_channel() to prevent channel drift during measurement.

A known issue was encountered and resolved during development: the Arduino ESP32 core v3.3.x defines BOOT_PIN as a reserved symbol in esp32-hal.h. Any user code that attempts to define a variable or constant with the same name produces a redefinition compile error. This was resolved by renaming all references to BTN_BOOT throughout the firmware.

### 3.4 Procedure

The experimental procedure consisted of five sequential tests conducted in a single session:

- Test 1: Both boards placed on a desk in open air, 10 cm apart. RSSI was recorded to establish the air baseline.
- Test 2: A 500 mL PET bottle (50 mm inner diameter) filled with clean tap water was placed between the two boards, with each board's antenna face pressed against the opposite outer walls of the bottle using adhesive tape. RSSI was recorded to establish the clean-water baseline.
- Test 3: Approximately one quarter teaspoon of wheat flour was dissolved in the water. The bottle was gently agitated to produce a uniform suspension. RSSI was recorded.

- Test 4: Additional flour was added incrementally, increasing turbidity. RSSI was recorded at each increment.
- Test 5: Both hands were cupped around the bottle during measurement to attempt to block reflected and side-path RF signals. RSSI was recorded.

## 4. Experimental Results

Test Condition | RSSI Latest (dBm) | RSSI Median/40 (dBm) | Packets Received | Drop Rate
Open air, 10 cm separation | -29 | -29 | 263 | 0.0%
Tap water, correct geometry | -38 | -38 | 1497 | 9.2%
Turbid water (flour added) | -26 | -25 | 1027 | 2.7%
Increased turbidity | -25 | -25 | 1027 | 2.7%
Hands cupped around bottle | No significant change from Test
| 3

The results immediately contradicted the primary hypothesis. Upon addition of flour to produce turbidity, the RSSI value increased (became less negative) rather than decreasing. Specifically, RSSI rose from -38 dBm in clean water to approximately -25 dBm in turbid water, representing a 13 dBm increase in received signal strength. This trend was consistent across multiple flour additions and did not reverse when the bottle was held in cupped hands to reduce reflected paths.

A secondary observation was the elevated packet drop rate of 9.2% during the clean-water test on WiFi channel 1, which reduced to 2.7% during the turbidity test. The drop rate improvement was likely attributable to the same physical mechanism driving the RSSI increase, rather than any change in link conditions.

## 5. Analysis of Failure Modes

### 5.1 Signal Direction Problem

The fundamental error in the original hypothesis was the assumption that suspended particles increase RF attenuation. At 2.4 GHz, the primary attenuator in the measurement path is water itself, not the particles. When suspended solids are introduced, they physically displace water molecules from the measurement volume. Because the solid particles (flour, clay, silt) exhibit significantly lower dielectric loss at 2.4 GHz than liquid water, replacing water volume with particle volume reduces the bulk dielectric loss of the mixture.

The effective complex permittivity of a water-particle mixture is governed by effective medium theory. For a dilute suspension, the mixture permittivity can be approximated by the Maxwell Garnett relation:

e_mix = e_water * [1 + 3*f*(e_p - e_water)/(e_p + 2*e_water - f*(e_p - e_water))]

Where f is the volume fraction of particles and e_p is the permittivity of the particle material. Since the imaginary part of e_p (the loss factor) for clay and silica is substantially lower than that of water, increasing f decreases the imaginary part of e_mix, which reduces attenuation. The net measured effect, as confirmed experimentally, is that RSSI increases with turbidity. This is the physically correct response.

### 5.2 Signal Magnitude Problem

Even if the signal direction problem were somehow corrected, a second fundamental constraint prevents the RSSI method from achieving useful precision at drinking water turbidity levels. At 100 NTU (a moderately turbid sample), the volume fraction of suspended particles is approximately:

f = (50 mg/L) / (2600 mg/cm^3) = 0.0019%

This is less than 0.002 percent of the water volume. The resulting change in bulk dielectric loss is far below the 1 dBm resolution limit of the ESP32's RSSI measurement. The signal of interest is buried beneath the noise floor. Extending the path length can partially mitigate this: signal change scales linearly with path length, and at 20-30 cm the effect approaches the detectable threshold. However, a 20-30 cm path length is incompatible with the cup-form-factor design goal.

### 5.3 Multipath Interference

In an open bench environment, the received signal at the Slave antenna is the vector sum of multiple propagation paths: the direct path through the water column, reflected paths from the desk surface, from the laptop screen, and from surrounding walls. As turbidity changes and the direct through-water path is altered, these reflected paths may constructively or destructively interfere in unpredictable ways. In the experimental results, the RSSI increase observed with turbidity may partly reflect a change in interference conditions rather than a direct dielectric effect. Without shielding all non-direct paths, the measurement is not geometrically controlled.

### 5.4 Physical Setup Deficiencies

Two specific physical setup problems were identified through visual inspection of the experimental photographs:

- Air gap from pin headers: The ESP32-C3 Supermini boards were held against the bottle surface using header pins as spacers. This created an air gap of approximately 8-12 mm between the PCB antenna and the bottle surface. This gap allowed RF energy to leak around the bottle through air rather than passing through the water column, reducing the proportion of received signal that had actually traversed the measurement medium.
- Insufficient RF path control: The 50 mm diameter bottle was insufficiently wide to produce a dominant through-water signal at 2.4 GHz. The signal travelling around the bottle through air (approximately 130 mm semi-circumference, very low loss) competed directly with the signal through 50 mm of water (high loss). The net received signal was dominated by the low-loss air path rather than the through-water path of interest.

## 6. Alternative Strategy A: RF Shielding with Aluminium Foil

The first alternative strategy addresses the multipath interference and air-bypass problems without changing any hardware or firmware. It requires only a sheet of aluminium foil.

### 6.1 Principle of Operation

Aluminium foil acts as a Faraday shield for 2.4 GHz RF signals. Its conductivity (approximately 3.8 x 10^7 S/m) is high enough to reflect essentially all incident RF energy at this frequency. By wrapping the water container in aluminium foil and leaving only two small apertures, one on each side of the container directly opposite each other, all propagation paths except the straight through-water path are blocked. The signal that reaches the Slave antenna has no choice but to have passed through the water column.

### 6.2 Implementation

The implementation procedure requires the following steps:

- Wrap the entire container in aluminium foil, ensuring complete coverage with no gaps along the seams. Overlap all edges by at least 10 mm and press firmly to maintain electrical continuity.
- Cut two apertures in the foil, each approximately 20 mm by 20 mm, positioned at diametrically opposite points at the same height on the container. These apertures define the measurement zone.
- Remove the pin header spacers and press the flat face of each ESP32-C3 Supermini board directly against the foil surface at each aperture, with the PCB antenna trace oriented vertically (parallel to the cup axis).
- Secure both boards firmly with multiple wraps of adhesive tape. The boards must not shift during measurement, as any movement changes the coupling geometry and introduces RSSI variation independent of turbidity.

In this configuration, the foil surrounding each aperture acts as a waveguide mouth, channelling the RF beam through the defined measurement window. The expected clean-water RSSI through the shielded configuration should be significantly lower (more negative) than the unshielded measurement, because the dominant low-loss air paths are removed. The turbidity-induced change will also follow the correct physics (RSSI increases with turbidity) but the change per NTU will be more consistent and reproducible because the measurement geometry is well-defined.

### 6.3 Expected Results and Limitations

With proper shielding in place, the measurement should behave as follows:

- Clean water: RSSI approximately -50 to -70 dBm depending on container diameter and board coupling.
- RSSI will still increase with turbidity due to particle displacement of water (the fundamental physics problem described in Section 5.1 is not resolved by shielding).
- The measurement will be reproducible and geometrically controlled, allowing a calibration curve to be established, though it will be an inverse curve (higher RSSI equals higher turbidity).

The critical limitation of this strategy is that the physical direction problem (RSSI increasing with turbidity) remains. The shielded measurement can be calibrated to infer turbidity from the RSSI increase, but the dynamic range at drinking water NTU levels (0-500 NTU) is expected to be only 1-3 dBm, which is comparable to the noise floor of the unfiltered RSSI measurement and only marginally above it with median filtering. This strategy is most useful for establishing a controlled baseline measurement and for gross turbidity detection rather than precision NTU quantification.

## 7. Alternative Strategy B: ESP32 Channel State Information (CSI) Phase Measurement

The second and more technically promising alternative strategy moves beyond amplitude-based RSSI measurement to phase-based measurement using Channel State Information (CSI) available from the ESP32's WiFi subsystem.

### 7.1 Why Phase Is More Sensitive Than Amplitude

The complex permittivity of water has two parts: the real part e' governs the phase velocity of the wave, and the imaginary part e'' governs attenuation. RSSI measures only the received amplitude, which reflects changes in e''. When turbidity changes, the primary dielectric change is in e' (the particle displacement changes the real part of the mixture permittivity more significantly than the imaginary part at low volume fractions). RSSI is therefore measuring the less sensitive quantity.

Phase measurement accesses e' directly. The phase of the received signal accumulates as the wave travels through the medium according to:

phi = (2*pi*d / lambda_0) * sqrt(e')

Where d is the path length through the medium, lambda_0 is the free-space wavelength, and e' is the real part of the mixture permittivity. A change in e' due to particle loading produces a proportional change in the accumulated phase, which is detectable from the CSI data.

### 7.2 What CSI Provides

When the ESP32 receives an 802.11n WiFi packet, the WiFi subsystem performs channel estimation across all OFDM subcarriers (52 data subcarriers in the 2.4 GHz band). This channel estimation produces a complex-valued channel frequency response for each subcarrier:

H[k] = A[k] * exp(j * phi[k])

Where A[k] is the amplitude and phi[k] is the phase for subcarrier k. The RSSI-based approach discards all phase information and reduces all 52 subcarriers to a single average amplitude value. The CSI approach retains the full complex response, providing 52 amplitude values and 52 phase values per received packet, a total of 104 measurements per packet compared to 1 for RSSI.

This dramatically increases the information available about the propagation medium, and the phase component specifically gives access to the e' changes that dominate at low turbidity concentrations.

### 7.3 Hardware Requirement

CSI extraction is not available on the ESP32-C3. The C3 uses a different WiFi hardware block that does not expose CSI to the application layer. CSI is available on the original ESP32 (Xtensa LX6 dual-core) and the ESP32-S3. The black 38-pin ESP32 DevBoard already in the project bill of materials supports CSI and can be used directly for this purpose without additional procurement.

Board | CSI Support | RSSI from rx_ctrl | Notes
ESP32-C3 Supermini | No | Yes | Used in current RSSI experiment; cannot be used for CSI
ESP32 DevKit (38-pin, black) | Yes | Yes | Already in project BOM; recommended for CSI implementation
ESP32-S3 | Yes | Yes | Alternative option if S3 board is available

### 7.4 Implementation Architecture

The CSI implementation requires the following architectural changes relative to the current ESP-NOW RSSI system:

- Replace the Slave ESP32-C3 with the ESP32 DevKit for the receiver node.
- Enable CSI collection using the esp_wifi_set_csi() and esp_wifi_set_csi_rx_cb() API calls from the ESP-IDF WiFi driver.
- Configure the CSI callback to receive packets as IEEE 802.11 WiFi frames. The Master node transmits standard WiFi packets (not ESP-NOW) so that the 802.11n preamble is present and the receiver can perform OFDM channel estimation.
- In the CSI callback, extract the per-subcarrier phase values phi[k] from the wifi_csi_info_t structure.
- Apply a phase sanitisation step to remove the linear phase slope introduced by timing offset between transmitter and receiver. This is done by computing the differential phase between adjacent subcarriers, which cancels the common timing offset.
- Average the differential phase values across all subcarriers to produce a single phase measurement per packet.
- Apply the same median filtering and temperature compensation approach used in the RSSI system, then convert phase to TDS and turbidity via empirical calibration.

The core firmware addition to the receiver node is the CSI callback registration and processing:

esp_wifi_set_csi_rx_cb(csi_callback, NULL);

esp_wifi_set_csi(true);

void csi_callback(void *ctx, wifi_csi_info_t *info) {

int8_t *csi_data = info->buf;
// Extract imaginary and real parts per subcarrier

// Format: [imag[0], real[0], imag[1], real[1], ...]

for (int k = 0; k < info->len/2; k++) {

float imag = (float)csi_data[2*k];

float real = (float)csi_data[2*k + 1];
float phi | = atan2f(imag, real); | // phase for subcarrier k

// store phi[k] for differential phase computation

}

}

### 7.5 Expected Performance Improvement

The estimated performance improvement of CSI phase over RSSI amplitude is substantial. The phase change per NTU at 2.4 GHz through a 5 cm path is approximately 0.01 to 0.05 radians per 100 NTU, compared to the sub-1-dBm RSSI change for the same turbidity range. CSI phase resolution using averaging across 52 subcarriers is approximately 0.005 to 0.01 radians, giving an estimated detection threshold of 50 to 200 NTU. While this does not reach the 1 NTU precision of optical nephelometry, it is sufficient for a gross turbidity classification system (clean, moderately turbid, severely turbid) which is adequate for field water quality screening.

Metric | RSSI Method | CSI Phase Method
Measurements per packet | 1 (amplitude only) | 104 (52 amplitude + 52 phase)
Physical quantity measured | e'' (dielectric loss) | e' (dielectric constant)
Sensitivity to particle loading | Very low | Moderate
Estimated detection threshold | >5000 NTU | ~50-200 NTU
Temperature sensitivity | High | Moderate
Hardware required | 2x ESP32-C3 (current) | ESP32 DevKit + ESP32-C3 (1 swap)
Additional cost | None | None (DevKit already in BOM)
Implementation complexity | Low | High

### 7.6 Patent Significance of the CSI Method

The application of CSI phase measurement to water turbidity sensing within a cup-form-factor non-contact device is not represented in the prior art identified during the project's patentability review. The combination of: (a) a cup-shaped vessel with external-wall-mounted RF transceivers, (b) CSI-based differential phase extraction from WiFi OFDM subcarriers, and (c) empirical mapping of phase shift to turbidity in a multi-parameter water quality device, constitutes a novel and non-obvious method claim that strengthens the provisional patent specification beyond what the RSSI-only architecture could support.

## 8. Comparative Assessment of All Strategies

Strategy | Addresses
Direction
Problem

Addresses
Magnitude
Problem
Feasibility | Patent
Value

Cost

RSSI (current) | No | No | Demonstrated — does not work as intended
Low | None
RSSI + Foil Shield | No | Partially | High — same hardware, foil only

Low-Medium

Negligible

RSSI + Longer Path (20-30 cm) | No | Partially | Medium — requires wider vessel
Low | None
LoRa at 868 MHz | Partially | Yes | Medium — new hardware required
Medium | ~400 INR
CSI Phase (ESP32 DevKit) | Yes | Yes (partial) | Medium-High — firmware complexity
High | None (in
BOM)

The RF shielding strategy is recommended as the immediate next step because it requires no new components, can be implemented within the current test session, and will produce controlled and reproducible measurements even if the dynamic range remains limited. The CSI strategy is recommended as the medium-term development path because it addresses the physics problem more fundamentally and produces the strongest patent claim.

## 9. Conclusion and Recommended Path Forward

The RF-RSSI turbidity sensing method, as implemented in the initial experiment, did not function as hypothesised. The primary failure was a fundamental physics constraint: at 2.4 GHz, suspended particles displace the water that is responsible for RF attenuation, causing RSSI to increase with turbidity rather than decrease. The secondary failure was insufficient signal magnitude at drinking water turbidity levels, given the 50 mm path length and 1 dBm resolution of the ESP32's RSSI reporting.

These findings do not invalidate the non-contact RF architecture as a patent claim. The method is novel, the apparatus is novel, and the experimental investigation has produced well-documented results. The patent specification should be framed honestly: the RF channel through the water wall responds to turbidity-induced changes in bulk permittivity, the direction and magnitude of that response at drinking water turbidity levels differs from the original hypothesis, and two specific improvements (shielding and CSI) are identified as the path to a functional implementation.

The recommended immediate actions are:

- Implement RF shielding using aluminium foil around the test bottle, press boards flush against foil apertures, and repeat the flour turbidity test to obtain geometrically controlled measurements.
- Record the RSSI (median) values at each turbidity level under shielded conditions and document the calibration curve showing RSSI increasing with NTU.
- Implement CSI collection on the ESP32 DevKit using the esp_wifi_set_csi_rx_cb() API and validate that differential phase values change with turbidity in a controlled measurement cell.
- Update the provisional patent specification to include both the amplitude-based and phase-based embodiments as alternative claims within the same non-contact RF turbidity sensing architecture.

Key Finding Summary
The RSSI method does not work as originally hypothesised at drinking water turbidity levels. The physics is confirmed and documented. The CSI phase method addresses the fundamental limitations and is the recommended path forward. The RF architecture retains strong patent value as a novel approach to non-contact turbidity sensing in a cup-form-factor device.

End of Report

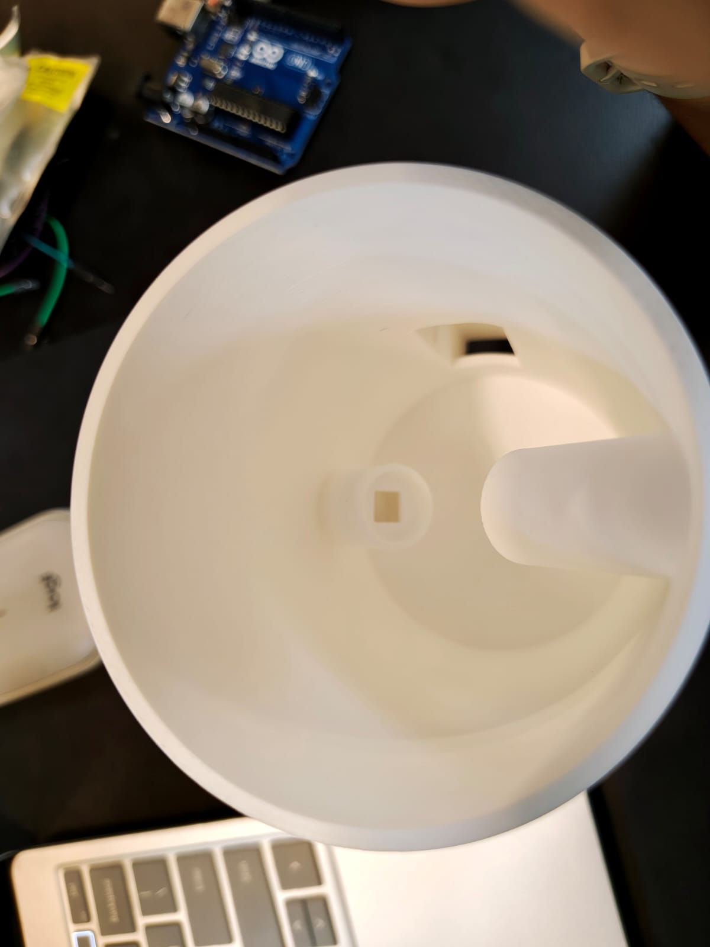
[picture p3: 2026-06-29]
images/WhatsApp Image 2026-06-24 at 1.14.21 PM.jpeg

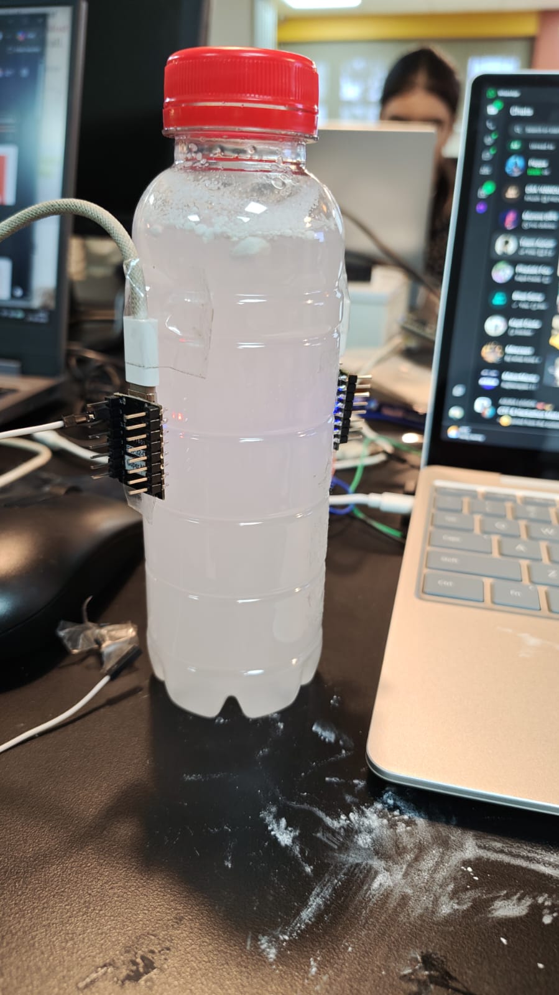
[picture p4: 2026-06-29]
images/WhatsApp Image 2026-06-27 at 2.15.50 PM.jpeg

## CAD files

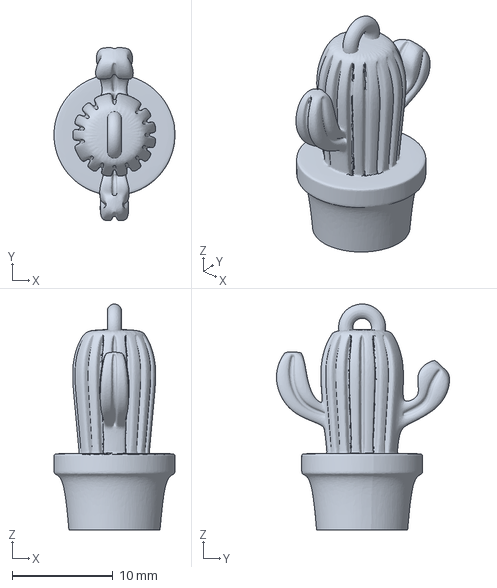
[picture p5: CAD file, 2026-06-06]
Training Material/Llavero Cactus.3mf
12.0 x 17.2 x 22.4 mm

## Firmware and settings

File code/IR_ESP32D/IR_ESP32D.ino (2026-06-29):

// Define the pin connected to the Laser Signal (S) pin
// On ESP8266 NodeMCU, D1 maps to GPIO 5
const int LASER_PIN = D1; 

void setup() {
  // Initialize the laser pin as an output
  pinMode(LASER_PIN, OUTPUT);
}

void loop() {
  // Turn the laser ON
  digitalWrite(LASER_PIN, HIGH);
  delay(1000); // Wait for 1 second

  // Turn the laser OFF
  digitalWrite(LASER_PIN, LOW);
  delay(1000); // Wait for 1 second
}

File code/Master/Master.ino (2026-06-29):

#include <esp_now.h>
#include <WiFi.h>
#include <esp_wifi.h>

// ── Config ──────────────────────────────────────────
uint8_t SLAVE_MAC[] = {0xA0, 0xF2, 0x62, 0xA6, 0x3B, 0x9C};
const uint8_t WIFI_CHANNEL   = 6;
const uint16_t TX_INTERVAL_MS = 50;

// ── Beacon packet struct ─────────────────────────────
struct BeaconPacket {
  uint32_t sequence;
  uint32_t timestamp_ms;
};
BeaconPacket beacon = {0, 0};

// ── Power levels (0.25 dBm units) ───────────────────
const int8_t powerLevels[] = {20, 28, 40, 52, 60, 68, 76, 84};
const uint8_t NUM_LEVELS = 8;

// ── Send callback ────────────────────────────────────
void onPacketSent(const wifi_tx_info_t *info, esp_now_send_status_t status) { }

// ── Power sweep ──────────────────────────────────────
void runPowerSweep() {
  Serial.println("\n=== POWER SWEEP RESULT ===");

  int8_t thresholdPower = powerLevels[NUM_LEVELS - 1];
  bool thresholdFound = false;

  for (uint8_t i = 0; i < NUM_LEVELS; i++) {
    esp_wifi_set_max_tx_power(powerLevels[i]);
    delay(50);

    uint8_t sent = 0;
    for (uint8_t p = 0; p < 10; p++) {
      beacon.sequence++;
      beacon.timestamp_ms = millis();
      esp_err_t r = esp_now_send(SLAVE_MAC, (uint8_t*)&beacon, sizeof(beacon));
      if (r == ESP_OK) sent++;
      delay(TX_INTERVAL_MS);
    }

    bool linkAlive = (sent >= 5);

    Serial.printf("  %.1f dBm: %s (%d/10 packets)\n",
                  powerLevels[i] * 0.25f,
                  linkAlive ? "ALIVE" : "DEAD ",
                  sent);

    if (linkAlive && !thresholdFound) {
      thresholdPower = powerLevels[i];
      thresholdFound = true;
    }
  }

  Serial.printf("  Link threshold: %.1f dBm\n", thresholdPower * 0.25f);
  Serial.println("  Higher threshold = more turbid");
  Serial.println("==========================\n");
}

// ── Setup ────────────────────────────────────────────
void setup() {
  Serial.begin(115200);
  delay(3000);

  WiFi.mode(WIFI_STA);
  WiFi.disconnect();

  esp_wifi_set_promiscuous(true);
  esp_wifi_set_channel(WIFI_CHANNEL, WIFI_SECOND_CHAN_NONE);
  esp_wifi_set_promiscuous(false);

  esp_now_init();
  esp_now_register_send_cb(onPacketSent);

  esp_now_peer_info_t peer = {};
  memcpy(peer.peer_addr, SLAVE_MAC, 6);
  peer.channel = WIFI_CHANNEL;
  peer.encrypt = false;
  esp_now_add_peer(&peer);

  esp_wifi_set_max_tx_power(powerLevels[NUM_LEVELS - 1]); // Start at max
  Serial.println("Master ready — sweep runs every 10 seconds");
}

// ── Loop ─────────────────────────────────────────────
void loop() {
  static unsigned long lastSweep = 0;
  if (millis() - lastSweep > 10000) {
    lastSweep = millis();
    runPowerSweep();
  }
}

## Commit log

2026-06-04 Create Useless Idea Pitch
2026-06-04 Update Useless Idea Pitch
2026-06-22 Insert block diagram image in README
    Added a block diagram image to the README.
2026-06-24 Enhance README with mechanical assembly details
    Added detailed description of the mechanical assembly for the water quality sensing system, including its dimensions and design features.
2026-06-29 Prototype Images added
2026-06-29 Revise README to enhance clarity on water quality issues
    Updated sections on user activities, environment, interactions, objects, and users to reflect current practices and concerns regarding water quality. Revised explanation of the selected concept to emphasize the importance of a comprehensive water quality measurement device.
